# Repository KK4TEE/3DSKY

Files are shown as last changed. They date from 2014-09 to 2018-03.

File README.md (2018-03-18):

# 3DSKY

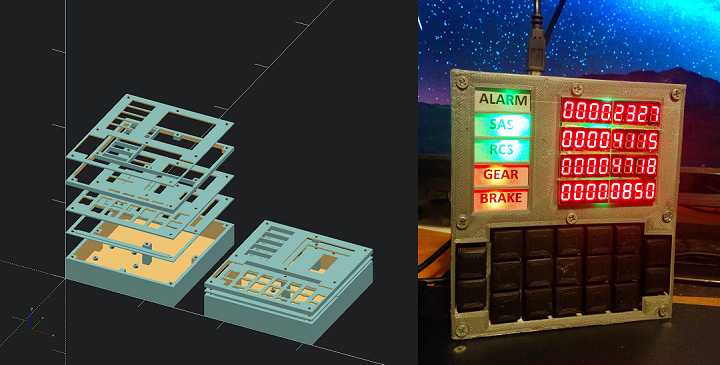
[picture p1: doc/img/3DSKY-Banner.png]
3DSKY An openSCAD design along with a fully printed and assembled 3DSKY


A 3D Kerbalized replica of NASA's [DSKY Apollo  Guidance Computer](https://en.wikipedia.org/wiki/Apollo_Guidance_Computer).

This replica is designed to be printed in PLA on a commodity 3D printer. It features mounting screws for an [Arduino Uno or Mega](https://en.wikipedia.org/wiki/Arduino) compatible micro-controller, as well as 7segment displays, LEDs for equipment status, and [Cherry MX](https://en.wikipedia.org/wiki/Cherry_(keyboards)) compatible keyboard switches for user input. The rear of the box has cutouts for the micro-controller's USB and DC barrel power connector.

Please also refer to my [Control-Panel](https://github.com/KK4TEE/Control-Panel) project which provides an interface for the 3DSKY to interface with the [Kerbal Space Program](https://kerbalspaceprogram.com) video game. The python script telemachus_plugin.py was an early attempt at this, but has been superseded by [Control-Panel](https://github.com/KK4TEE/Control-Panel).

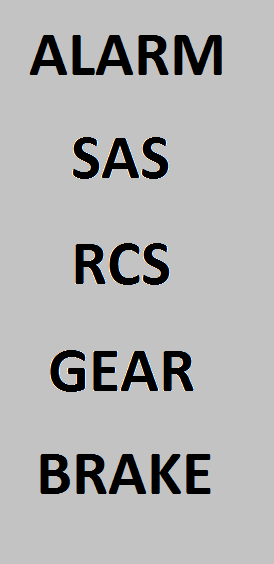
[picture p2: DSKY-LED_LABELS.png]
LED Labels
| DSKY-LED_LABELS.png is sized to fit into the space between the top cover and the top riser. You are welcome to adjust the image to show alternative status output with the LEDs. |  |
|:-----:|:---:|

## Media Coverage
This project was featured on [Kotaku](https://kotaku.com/guy-3d-prints-actual-working-flight-computer-for-kerbal-1636244174) and [3Ders.org](https://www.3ders.org/articles/20140919-redditor-3d-prints-an-actually-working-flight-computer-for-kerbal-space-program.html)

## Aditional Information
For additional pictures and in-progress pictures, please check out the [imgur album](https://imgur.com/a/6XkWy)

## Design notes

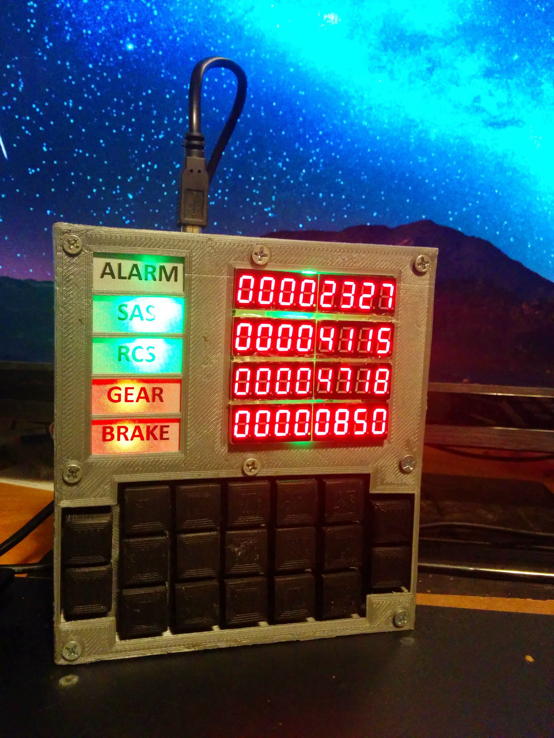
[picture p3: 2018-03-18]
doc/img/3DSKY-Complete.jpg

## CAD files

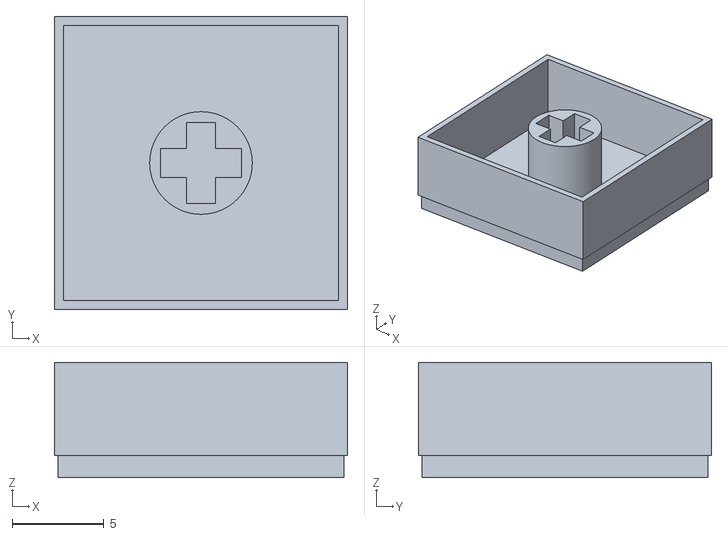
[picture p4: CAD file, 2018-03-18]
STL/DSKY-Keycap.stl
16.0 x 16.0 x 6.30

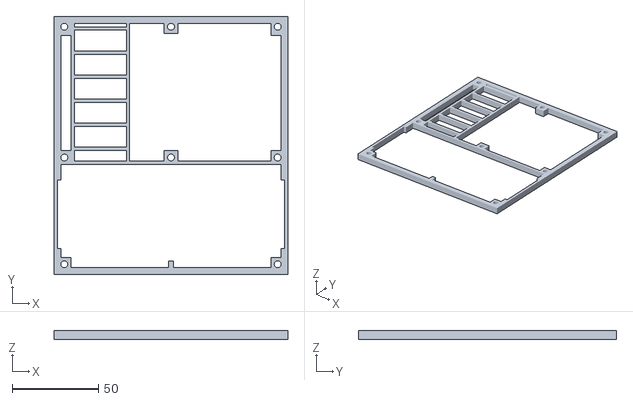
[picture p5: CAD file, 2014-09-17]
STL/DSKY-TopRiser.stl
136.0 x 150.0 x 5.00

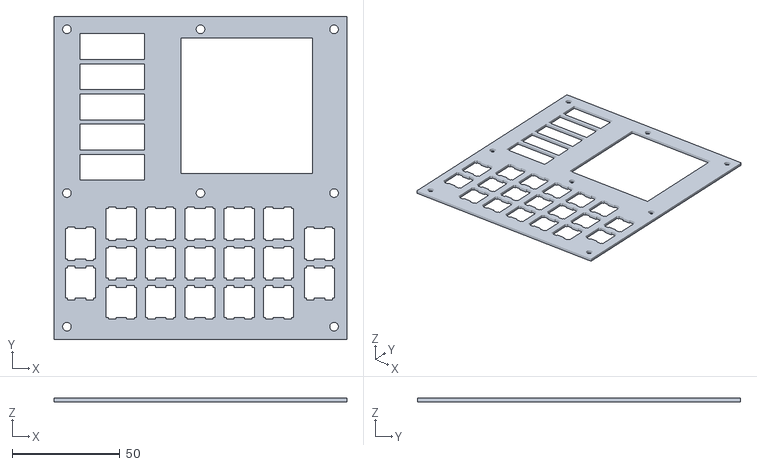
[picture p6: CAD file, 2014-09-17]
STL/DSKY-Keyframe.stl
136.0 x 150.0 x 1.80

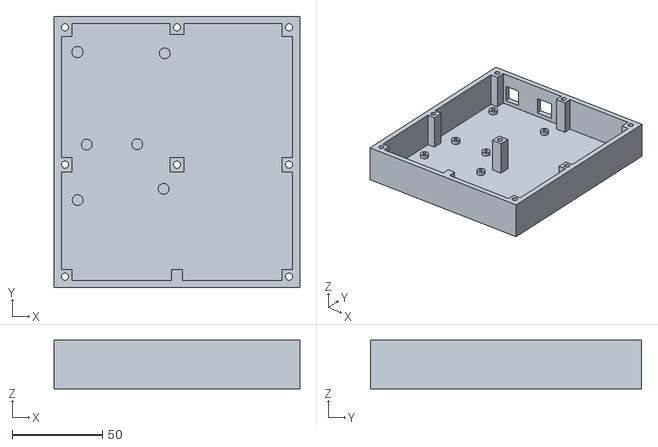
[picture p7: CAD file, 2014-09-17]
STL/DSKY-Base.stl
136.0 x 150.0 x 27.0

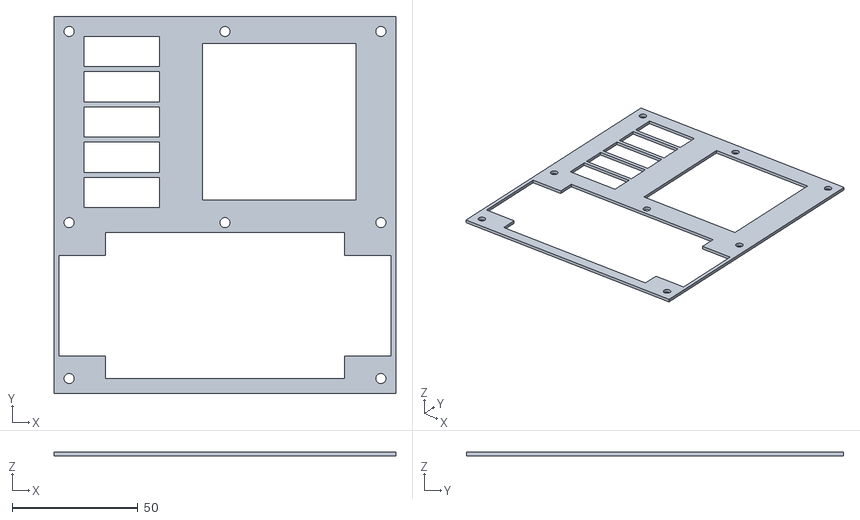
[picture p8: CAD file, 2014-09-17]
STL/DSKY-TopCover.stl
136.0 x 150.0 x 1.60

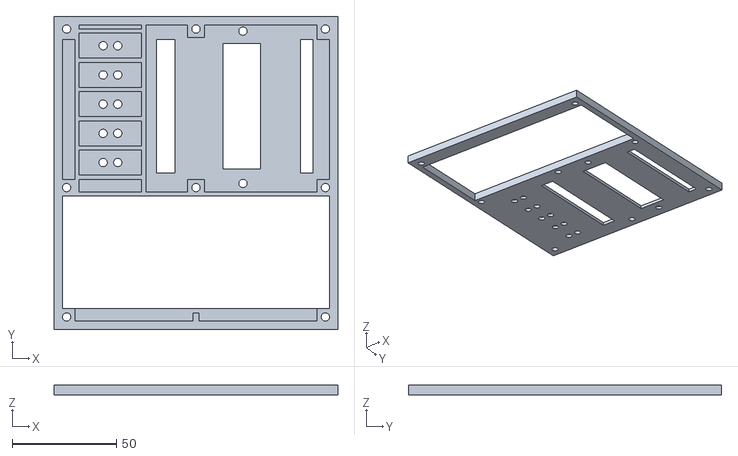
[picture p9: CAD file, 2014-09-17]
STL/DSKY-Mid.stl
136.0 x 150.0 x 5.00

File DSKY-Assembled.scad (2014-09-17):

use<DSKY-Base.scad>;
use<DSKY-Mid.scad>;
use<DSKY-Keyframe.scad>;
use<DSKY-TopRiser.scad>;
use<DSKY-TopCover.scad>;

numSBars = 5;
sHeight = 100;

color("silver"){
union(){
translate([0,0,0]) dskyBase();
translate([0,0,60]) dskyMid();
translate([0,0,90]) keyframe();
translate([0,0,120]) topRiser();
translate([0,0,160]) topCover();

translate([175,0,0]) dskyBase();
translate([175,0,27]) dskyMid();
translate([175,0,32]) keyframe(); 
translate([175,0,33.8]) topRiser();

translate([175,0,42.4]) topCover();

translate([13,65,160]) square([115, 76]);
translate([187,65,42.5]) square([115, 76]);
}}

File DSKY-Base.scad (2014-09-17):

use<dls/dev_boards.scad>;
module dskyBase()
{
difference() {
 union(){
	difference() {
		cube([136, 150, 27]);
		translate([10, 10, 2]){
			cube([110, 130, 29]);}

		translate([4, 10, 2]){
			cube([128, 54, 29]);}
		translate([4, 72, 2]){
			cube([128, 67, 29]);}

		translate([10, 4, 2]){
			cube([116, 142, 29]);}
		 

		
	}
	//middle screw support
	translate([64, 64, 0]){ //center
		cube([8, 8, 27,]);}
	translate([64, 140, 0]){ //upper mid
		cube([8, 9, 27,]);}
	translate([65, 4, 0]){ //lower mid
		cube([6, 6, 27,]);}

	//Arduino support
		translate([10, 146,2]){ //top left corner
			arduinoMounts(3.1,3);
			}
	//Arduino Mockups
	//translate([37,94,4])rotate(180){arduino_mega();}
	//translate([37,112,4])rotate(180)arduino_uno();

 			
	}	
//Screw Holes
		translate([6, 6,0]){
				cylinder(h=sHeight,r=2, center=true, $fn=100);}
		translate([130, 6,0]){
				cylinder(h=sHeight,r=2, center=true, $fn=100);}
		translate([6, 144,0]){
				cylinder(h=sHeight,r=2, center=true, $fn=100);}
		translate([130, 144,0]){
				cylinder(h=sHeight,r=2, center=true, $fn=100);}
		translate([6, 68,0]){
				cylinder(h=sHeight,r=2, center=true, $fn=100);}
		translate([130, 68,0]){
				cylinder(h=sHeight,r=2, center=true, $fn=100);}
		translate([68, 144,0]){
				cylinder(h=sHeight,r=2, center=true, $fn=100);}
		translate([68, 68,0]){
				cylinder(h=sHeight,r=2, center=true, $fn=100);}
		//USB
		translate([41.7, 145.9, 5]){
			cube([13.4, 15, 12.2]);}
		//Power
		translate([12.4, 145.9,5]){ 
			cube([11.6, 15, 12.2]);}


	//Arduino Mounts
		translate([10, 146,2]){ //top left corner
			arduinoMounts(3.1,1.3);
			}
}
}


module arduinoMounts(hightIN, radiusIN){
//Arduino support, DC jack is near the origin
		translate([2.9, -15.7, (hightIN/2)-0.5]){ //top left
				cylinder(h=hightIN,r=radiusIN+0.1, center=true, $fn=100);}
		translate([51.2, -16.4, (hightIN/2)-0.5]){ //top right
				cylinder(h=hightIN,r=radiusIN, center=true, $fn=100);}
		translate([8.0, -66.9,(hightIN/2)-0.5]){ //bottom left
				cylinder(h=hightIN,r=radiusIN, center=true, $fn=100);}
		translate([36.0, -66.7, (hightIN/2)-0.5]){ //bottom right
				cylinder(h=hightIN,r=radiusIN, center=true, $fn=100);}
	//mega extension
		translate([3, -97.6, (hightIN/2)-0.5]){ //mega bottom left
				cylinder(h=hightIN,r=radiusIN, center=true, $fn=100);}
		translate([50.6, -91.4, (hightIN/2)-0.5]){ //mega bottom right
				cylinder(h=hightIN,r=radiusIN, center=true, $fn=100);}

}

sHeight = 100;
dskyBase();

 

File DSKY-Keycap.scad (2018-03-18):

module frame(){
	translate( [0,0, -1.2/2] )
		cube( size=[15.6,15.6,1.2], center=true );
	translate( [0,0, 5.1/2] ){
		difference(){
			cube( size=[16,16,5.1], center=true );
			cube( size=[15,15,5.1], center=true );
		}
	}
}

module stem(){
	height = 5.1;
	translate([0,0,height/2]){
		difference(){
			cylinder( h=height, r=5.6/2, center=true, $fn=360 );
			cube( size=[1.6,4.4,height+2], center=true );
			cube( size=[4.4,1.6,height+2], center=true );
		}
	}
}

frame();
stem();

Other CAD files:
DSKY-Keyframe.scad
DSKY-Mid.scad
DSKY-TopCover.scad
DSKY-TopRiser.scad

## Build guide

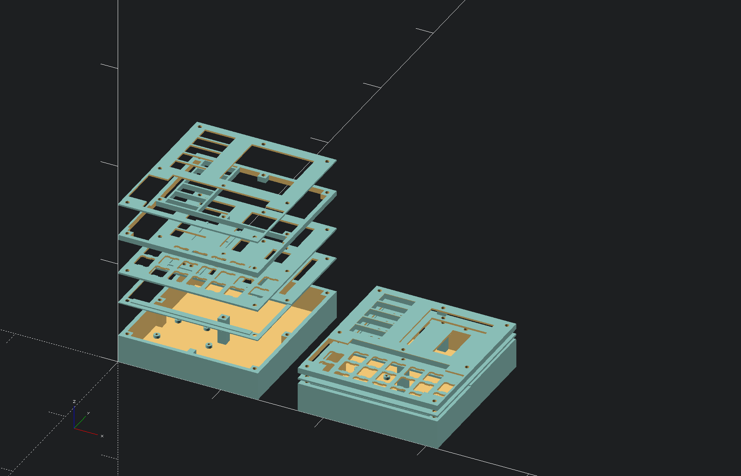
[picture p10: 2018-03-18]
doc/img/3DSKY-Assembled-openSCAD.png

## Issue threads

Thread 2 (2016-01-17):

key caps

depperson, 2016-01-17:
What did you use for the key caps?

KK4TEE, 2016-01-19:
I used a 3D printed flat square keycap with a cherry MX compatible base. It
looks like I forgot to include it with the rest of the model files, but
I'll see if I can track it down and upload it for you.

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

marccardinal, 2017-05-03:
Did you have a chance to take a look?

KK4TEE, 2018-03-18:
Found it! It's now included along with the other openSCAD files.

mcardinalupgrade, 2018-03-18:
Thanks Man!

Closed 2018-03-18.

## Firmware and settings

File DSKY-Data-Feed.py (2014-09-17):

#DSKY-Data-Feed
'''This is a complete rewrite of my previous Flight Terminal program.
This is designed to work with the 3d printed DSKY replica, but it should work
with any sort of similar program.'''
import math
import time
import config
import telemachus_plugin as tele
import telemachus_plugin

try:
    import serial
except:
    print 'PySerial does not seem to be installed'

try:
    ser = serial.Serial(
        port=config.arduinoSerialPort(),
        #port='COM3',
        #baudrate=115200, # Causes the arduino buffer to fill up
        #baudrate=28800, #doesn't seem to work at all
        baudrate=9600,  # Seems to be working well
       # parity=serial.PARITY_ODD,
       # stopbits=serial.STOPBITS_TWO,
       # bytesize=serial.SEVENBITS
    )
    arduinoConnected = True
    print 'Serial device connected at ' + config.arduinoSerialPort()
except:
    arduinoConnected = False
    print 'Unable to connect to arduino at ' + config.arduinoSerialPort()
print 'Waiting 3 for Arduino to boot...'
time.sleep(3)

def getFlightData(dIN):
    # Try to update the dictionary with live data. If any of it fails for any
    # reason, return the original dictionary and set the 'Radio Contact' key
    # to false.
    d = {'Zero': 0}
    try:
        d['MET'] = float(tele.read_missiontime())
        d['ASL'] = int(tele.read_asl())
        d['Height From Terrain'] = int(tele.read_heightFromTerrain())
        d['Body'] = str(tele.read_body())
        d['Ap'] = int(tele.read_apoapsis())
        d['Pe'] = int(tele.read_periapsis())
        d['Time to Ap'] = float(tele.read_time_to_ap())
        d['Time to Pe'] = float(tele.read_time_to_pe())
        d['Eccentricity'] = float(tele.read_eccentricity())
        d['Inclination'] = float(tele.read_inclination())
        d['Orbital Period'] = float(tele.read_orbitalperiod())
        d['Vertical Speed'] = float(tele.read_verticalspeed())
        d['Surface Speed'] = float(tele.read_surfacespeed())
        d['Pitch'] = float(tele.read_facing('pitch'))
        d['Yaw'] = float(tele.read_facing('yaw'))
        d['Roll'] = float(tele.read_facing('roll'))
        d['Throttle'] = float(tele.read_throttle())

        d['Brake Status'] = int(tele.brake(2))
        d['Gear Status'] = int(tele.gear(2))
        d['SAS Status'] = int(tele.sas(2))
        d['RCS Status'] = int(tele.rcs(2))
        d['Light Status'] = int(tele.light(2))

        d['ElectricCharge'] = float(tele.read_resource('ElectricCharge'))
        d['Max ElectricCharge'] = float(tele.read_resource_max(
            'ElectricCharge'))
        d['LiquidFuel'] = float(tele.read_resource('LiquidFuel'))
        d['Max LiquidFuel'] = float(tele.read_resource_max('LiquidFuel'))
        d['Oxidizer'] = float(tele.read_resource('Oxidizer'))
        d['Max Oxidizer'] = float(tele.read_resource_max('Oxidizer'))
        d['SolidFuel'] = float(tele.read_resource('SolidFuel'))
        d['Max SolidFuel'] = float(tele.read_resource_max('SolidFuel'))
        d['MonoPropellant'] = float(tele.read_resource('MonoPropellant'))
        d['Max MonoPropellant'] = float(tele.read_resource_max('MonoPropellant'))
        # If you are playing with realism mods, uncomment these as needed
        #d['Oxygen'] = float(tele.read_resource('Oxygen'))
        #d['Max Oxygen'] = float(tele.read_resource_max('Oxygen'))
        #d['LiquidOxygen'] = float(tele.read_resource('LiquidOxygen'))
        #d['Max LiquidOxygen'] = float(tele.read_resource_max('LiquidOxygen'))
        #d['LiquidH2'] = float(tele.read_resource('LiquidH2'))
        #d['Max LiquidH2'] = float(tele.read_resource_max('LiquidH2'))
        #d['MMH'] = float(tele.read_resource('MMH'))
        #d['Max MMH'] = float(tele.read_resource_max('MMH'))
        #d['N2O4'] = float(tele.read_resource('N2O4'))
        #d['Max N2O4'] = float(tele.read_resource_max('N2O4'))

        d['Previous Radio Contact'] = dIN['Radio Contact']
        d['Radio Contact'] = True

        #Clean up the data types
        if d['SAS Status'] == 1:
            d['SAS Status'] = True
        elif d['SAS Status'] == 0:
            d['SAS Status'] = False
        else:
            d['SAS Status'] = 'Error'
        if d['RCS Status'] == 1:
            d['RCS Status'] = True
        else:
            d['RCS Status'] = False
        if d['Light Status'] == 1:
            d['Light Status'] = True
        else:
            d['Light Status'] = False
        if d['Gear Status'] == 1:
            d['Gear Status'] = True
        elif d['Gear Status'] == 0:
            d['Gear Status'] = False
        if d['Brake Status'] == 1:
            d['Brake Status'] = True
        elif d['Brake Status'] == 0:
            d['Brake Status'] = False

        print "Flight data updated."
        return d


    except:
        dIN['Previous Radio Contact'] = dIN['Radio Contact']
        dIN['Radio Contact'] = False
	print "An error occured while requesting flight data"
        del d
        return dIN


def buttonHandler():
    # Reads memB for which buttons are pressed, then sends
    # calls to telemachus as needed.
    global memB
    global memBOLD
    if memB[1] == '1' and memB[1] != memBOLD[1]:
        if (memB[7] == '1'):  # Check the safety
            tele.stage()

    if memB[0] == '1' and memB[0] != memBOLD[0]:
        if memB[7] == '1':  # Check the safety
            tele.abort()

    if int(memB[2]) == 1 and memB[2] != memBOLD[2]:
        # Toggle gear based on what we did last time
        if ps['Gear Status'] is True:
            # Telemachus does not yet read gear status
            tele.gear(0)
            ps['Gear Status'] = False
        elif ps['Gear Status'] is False:
            tele.gear(1)
            ps['Gear Status'] = True

    if int(memB[3]) == 1 and memB[3] != memBOLD[3]:
        # Toggle Light based on the Telemachus reading
        if fd['Light Status'] is True:
            tele.light(0)
        elif fd['Light Status'] is False:
            tele.light(1)

    if int(memB[4]) == 1 and memB[4] != memBOLD[4]:
        # Toggle brake based on what we did last time
        if ps['Brake Status'] is True:
            # Telemachus does not yet read brake status
            tele.brake(0)
            ps['Brake Status'] = False
        elif ps['Brake Status'] is False:
            tele.brake(1)
            ps['Brake Status'] = True

    if int(memB[5]) == 1 and memB[5] != memBOLD[5]:
        # Toggle RCS based on the Telemachus reading
        if fd['RCS Status'] is True:
            tele.rcs(0)
        elif fd['RCS Status'] is False:
            tele.rcs(1)

    if int(memB[6]) == 1 and memB[6] != memBOLD[6]:
        # Toggle SAS based on the Telemachus reading
        if fd['SAS Status'] is True:
            tele.sas(0)
        elif fd['SAS Status'] is False:
            tele.sas(1)


def push_to_arduino(inputline):
    #Packet Size: 38 Bytes
    #Header "<"
    #memA[0] Program Select
    #memA[1] Red LEDs [Alarm, SAS, RCS, Gear, Brake, Case/Body*, Keyboard Backlight*]
    #memA[2] Green LEDs [Alarm, SAS, RCS, Gear, Brake, Case/Body*, Keyboard Backlight*]
    #memA[3] Not Used
    #memA[4-36] 7 Segment Display Digits, starting in the top left corner
    #Footer ">"

    # Send data to inside of a header and footer
    if len(inputline) is 36:
        ser.write('<' + inputline + '>')
	print("Transmitting: " + '<' + inputline + '>')
    else:
        print 'Error: An amount other than 36 characters was passed to push_to_arduino'


def formatForArduino(mode):
    #Packet Size: 38 Bytes
    #Header "<"
    #memA[0] Program Select
    #memA[1] Red LEDs [Alarm, SAS, RCS, Gear, Brake, Case/Body*, Keyboard Backlight*]
    #memA[2] Green LEDs [Alarm, SAS, RCS, Gear, Brake, Case/Body*, Keyboard Backlight*]
    #memA[3] Not Used
    #memA[4-36] 7 Segment Display Digits, starting in the top left corner
    #Footer ">"

    if mode == 'Lamp Test':  # Light Test
        arduino['7r0 Data'] = '88888888'
        arduino['7r1 Data'] = '88888888'
        arduino['7r2 Data'] = '88888888'
        arduino['7r3 Data'] = '88888888'
        arduino['7r4 Data'] = '88888888'


    elif mode == 'Clock':
        '''There's something weird going on here that causes the code to
        take a full 300ms or so to loop. This requires further research.'''
        arduino['7r0 Data'] = '        '
        arduino['7r1 Data'] = str(time.strftime("%H %M %S"))
        arduino['7r2 Data'] = str(time.strftime(" %m  %d "))
        arduino['7r3 Data'] = str(time.strftime("  %Y  "))
        arduino['7r4 Data'] = '        '

    else:
        arduino['7r0 Data'] = str(int(round(fd["Time to Ap"]))).zfill(8)
        arduino['7r1 Data'] = str(int(round(fd["ASL"] / 100))).zfill(8)
        arduino['7r2 Data'] = str(int(round(fd["Ap"] / 100))).zfill(8)
        arduino['7r3 Data'] = str(int(round(fd["Pe"] / 100))).zfill(8)
        arduino['7r4 Data'] = str(int(round(fd["MET"]))).zfill(8)
	arduino['LEDG'] = 0
	if fd['Throttle'] > 0:
            arduino['LEDG'] += 1<<0
        if fd['SAS Status'] is True:
            arduino['LEDG'] += 1<<1
        if fd['RCS Status'] is True:
            arduino['LEDG'] += 1<<2
        if fd['Gear Status'] is True:
            arduino['LEDG'] += 1<<3
        if fd['Brake Status'] is True:
            arduino['LEDG'] += 1<<4
	if arduino['Backlight'] is True:
            arduino['LEDG'] += 1<<5
	print bin(arduino['LEDG'])
	arduino['LEDG'] = chr(arduino['LEDG'])

	arduino['LEDR'] = 0
	if fd['ElectricCharge'] < (fd['Max ElectricCharge'] / 10):
            arduino['LEDR'] += 1<<0
        if fd['SAS Status'] is False:
            arduino['LEDR'] += 1<<1
        if fd['RCS Status'] is False:
            arduino['LEDR'] += 1<<2
        if fd['Gear Status'] is False:
            arduino['LEDR'] += 1<<3
        if fd['Brake Status'] is False:
            arduino['LEDR'] += 1<<4
	print bin(arduino['LEDR'])
	arduino['LEDR'] = chr(arduino['LEDR'])



def clamp(num, minn, maxn):
    if num < minn:
        return minn
    elif num > maxn:
        return maxn
    else:
        return num


######################################################################################

# Flight Data Memory and other variables
fd = {  # Primary data storage
'MET': -1, 'ASL': -1, 'Ap': -1, 'Pe': -1, 'Time to Ap': -1, 'Time to Pe': -1,
'Eccentricity': -1, 'Inclination': -1, 'Orbital Period': -1,
'Vertical Speed': -1, 'Surface Speed': -1, 'Pitch': -1, 'Roll': -1, 'Yaw': -1,
'Height From Terrain': -1,
'Throttle': -1, 'SAS Status': -1, 'RCS Status': -1, 'Light Status': -1,
'Brake Status': -1, 'Gear Status': -1,
'ElectricCharge': -1, 'Max ElectricCharge': -1,
'LiquidFuel': -1, 'Max LiquidFuel': -1,
'Oxidizer': -1, 'Max Oxidizer': -1,
'SolidFuel': -1, 'Max SolidFuel': -1,
'MonoPropellant': -1, 'Max MonoPropellant': -1,
'Oxygen': -1, 'Max Oxygen': -1,  # Realisim Resources
'LiquidH2': -1, 'Max LiquidH2': -1,
'LiquidOxygen': -1, 'Max LiquidOxygen': -1,
'MMH': -1, 'Max MMH': -1,
'N2O4': -1, 'Max N2O4': -1,
'Radio Contact': False, 'Previous Radio Contact': False}

ps = {  # Program Settings
'Main Menu is Open': False, 'Main Menu Selection': 1, 'Slection Made': False,
'Display Mode': 'Standard',
'Flight Transceiver Active': True,
'Terminal Max Y': 25, 'Terminal Max X': 40,
'Arduino Sleep Marker': 0, 'Arduino Active': False, 'Button Sleep Marker': 0,
'flightData Sleep Marker': 0, 'Gear Status': False, 'Brake Status': False}

arduino = {  # Arduino Configurtion, using rows
'Program': str('Z'),
'LEDR': str('z'),
'LEDG': str('z'),
'Byte3': str('z'),
'7r0 Name': 'MET', '7r0 Data': str().zfill(8),
'7r1 Name': 'ASL', '7r1 Data': str().zfill(8),
'7r2 Name': 'Ap', '7r2 Data': str().zfill(8),
'7r3 Name': 'Pe', '7r3 Data': str().zfill(8),
'7r4 Name': 'Time to Ap', '7r4 Data': str().zfill(8),
'g0 Name': 'MET', 'g0 Data': str().zfill(1),
'Backlight': True
}

arduinoSleepMarker = 0
buttonSleepMarker = 0
flightDataSleepMarker = config.pollInterval()
memB = [0, 0, 0, 0, 0, 0, 0, 0, 0, 0, 0, 0, 0, 0, 0]  # Current serial input
memBOLD = [0, 0, 0, 0, 0, 0, 0, 0, 0, 0, 0, 0, 0, 0, 0]  # Old serial input

###############################################################################################
while True:
    loopStartTime = time.time()
    fd = getFlightData(fd)
    if arduinoConnected is True:
        formatForArduino('Telemetry')
        memA = (
            str(arduino['Program']) +
            str(arduino['LEDR']) +
            str(arduino['LEDG']) +
            str(arduino['Byte3']) +
            str(arduino['7r0 Data']) +
            str(arduino['7r1 Data']) +
            str(arduino['7r2 Data']) +
            str(arduino['7r3 Data'])

            )

        if arduinoSleepMarker > 0.10:
            try:
                push_to_arduino(memA)
            except:
                print "Error pushing to Arduino"
                pass
            finally:
                arduinoSleepMarker = 0
        '''
        if ser.inWaiting > 9:
            try:
                serCharIn = str(ser.read(1))
                if serCharIn == '<':
                    while n < 12:
                        serCharIn = str(ser.read(1))
                        if serCharIn == '>':
                            n = 0
                            ser.flushInput()
                            break
                        else:
                            memB[n] = serCharIn
                        n += 1
                        if n == 11:
                            ser.flushInput()
            except:
                ser.flushInput()'''
        ser.flushInput()
        if buttonSleepMarker > 0.1:
            buttonHandler()
            button_sleep_marker = 0
            memBOLD = list(memB)

    loopTimeOffset = config.pollInterval() + loopStartTime - time.time()
        # This can be used to slow the entire program down to cycle at a
        # given interval. This is a failsafe to prevent 100% utilization
    if loopTimeOffset > 0:
        time.sleep(loopTimeOffset)
    # Combined Bandwidth used based on interval:
    # 33ms = around 395 Packets/S, 345kbs
    # 25ms = around 500 Packets/S, 410kbs
    loopEndTime = time.time()
    loopTime = loopEndTime - loopStartTime
    arduinoSleepMarker += loopTime
    buttonSleepMarker += loopTime
    flightDataSleepMarker += loopTime

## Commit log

2014-09-17 Uploading OpenScad files
    [DSKY-Assembled.scad, DSKY-Base.scad, DSKY-Keyframe.scad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]
2014-09-17 Added .STL files for printing
    [DSKY-Base.stl, DSKY-Keyframe.stl, DSKY-Mid.stl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]
2018-03-18 Added images and README
    DSKY-LED_LABELS had actually been missing all these years. Finally uploaded.
2018-03-18 Found the Keycap file
    [DSKY-Keycap.scad]
2018-03-18 Added Keycap STL
    [DSKY-Keycap.stl]
